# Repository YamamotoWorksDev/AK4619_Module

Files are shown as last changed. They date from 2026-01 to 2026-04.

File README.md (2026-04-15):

# AK4619 Module
This is a module board for prototyping digital synthesizers or mixers, featuring a 4-channel audio codec (AK4619VN) that supports up to 192 kHz.

## How to buy
### 2x2
- [Tindie(International)](https://www.tindie.com/products/yamamotoworks/ak4619vn-codec-module-2x2/)  
- [BASE(Japan)](https://miyworks.base.shop/items/131805475)

### 1x4
- [Tindie(International)](https://www.tindie.com/products/yamamotoworks/ak4619vn-codec-module-1x4/)  
- [BASE(Japan)](https://miyworks.base.shop/items/139583333)

## Specifications
- Power: 5V input, onboard 3.3V regulator (AP7361)
- CODEC IC: [AK4619VN](https://www.akm.com/global/en/products/audio/audio-codec/ak4619vn/)
  - Channels: 4in/4out
  - Sample Rate: 192kHz(max.)
  - TDM Slave (expects external BCLK/LRCLK and MCLK)
- Audio Jack: [Green Thonkiconn Stereo 3.5mm Jack Socket](https://www.thonk.co.uk/shop/thonkiconn/)
- RESET IC: [ADM811](https://www.analog.com/en/products/adm811.html)
- Power IC: [AP7361EA-33E-13](https://www.diodes.com/assets/Datasheets/AP7361EA.pdf)

## Codec Initialization(Example)
```c
void AUDIO_Init_AK4619(uint32_t hz)
{
    uint8_t sndData[1] = {0x00};

    // AK4619 HW Reset
    HAL_GPIO_WritePin(CODEC_RESET_GPIO_Port, CODEC_RESET_Pin, 0);
    HAL_Delay(10);
    HAL_GPIO_WritePin(CODEC_RESET_GPIO_Port, CODEC_RESET_Pin, 1);
    HAL_Delay(500);

    // Audio I/F format
    sndData[0] = 0xAC;  // 1 010 11 00 (TDM, 32bit, TDM128 I2S compatible, Falling, Slow)
    HAL_I2C_Mem_Write(&hi2c3, (0b0010001 << 1), 0x01, I2C_MEMADD_SIZE_8BIT, sndData, sizeof(sndData), 10000);

    // Reset Control
    sndData[0] = 0x10;  // 000 1 00 00
    HAL_I2C_Mem_Write(&hi2c3, (0b0010001 << 1), 0x02, I2C_MEMADD_SIZE_8BIT, sndData, sizeof(sndData), 10000);

    // System Clock Setting (example: 96kHz)
    sndData[0] = 0x01;  // 00000 001 (96kHz)
    HAL_I2C_Mem_Write(&hi2c3, (0b0010001 << 1), 0x03, I2C_MEMADD_SIZE_8BIT, sndData, sizeof(sndData), 10000);

    // ADC Input Setting
    sndData[0] = 0x55;  // 01 01 01 01 (AIN1L, AIN1R, AIN4L, AIN4R)
    HAL_I2C_Mem_Write(&hi2c3, (0b0010001 << 1), 0x0B, I2C_MEMADD_SIZE_8BIT, sndData, sizeof(sndData), 10000);

    // DAC Input Select Setting
    // sndData[0] = 0x0E;  // 00 00 11 10 (ADC1 -> DAC1, ADC2 -> DAC2)
    sndData[0] = 0x04;  // 00 00 01 00 (SDIN2 -> DAC2, SDIN1 -> DAC1)
    HAL_I2C_Mem_Write(&hi2c3, (0b0010001 << 1), 0x12, I2C_MEMADD_SIZE_8BIT, sndData, sizeof(sndData), 10000);

    // Power Management
    sndData[0] = 0x37;  // 00 11 0 11 1
    HAL_I2C_Mem_Write(&hi2c3, (0b0010001 << 1), 0x00, I2C_MEMADD_SIZE_8BIT, sndData, sizeof(sndData), 10000);
}
```

## Application Example
- [JUMBLEQ](https://github.com/yamamo2shun1/JUMBLEQ)

## Size
### 2x2
ak4619_2x2_brd

### 1x4
ak4619_1x4_brd

## Photos
### 2x2
2x2 top
2x2 bottom

### 1x4
1x4 top
1x4 bottom

## License
The hardware design files in this repository are licensed under the
**CERN Open Hardware Licence Version 2 - Permissive (CERN-OHL-P-2.0)**.

Unless otherwise stated, the following are treated as hardware design files covered by CERN-OHL-P-2.0:

- KiCad schematic files
- PCB layout files

A copy of the license text is provided in the `LICENSE` file.

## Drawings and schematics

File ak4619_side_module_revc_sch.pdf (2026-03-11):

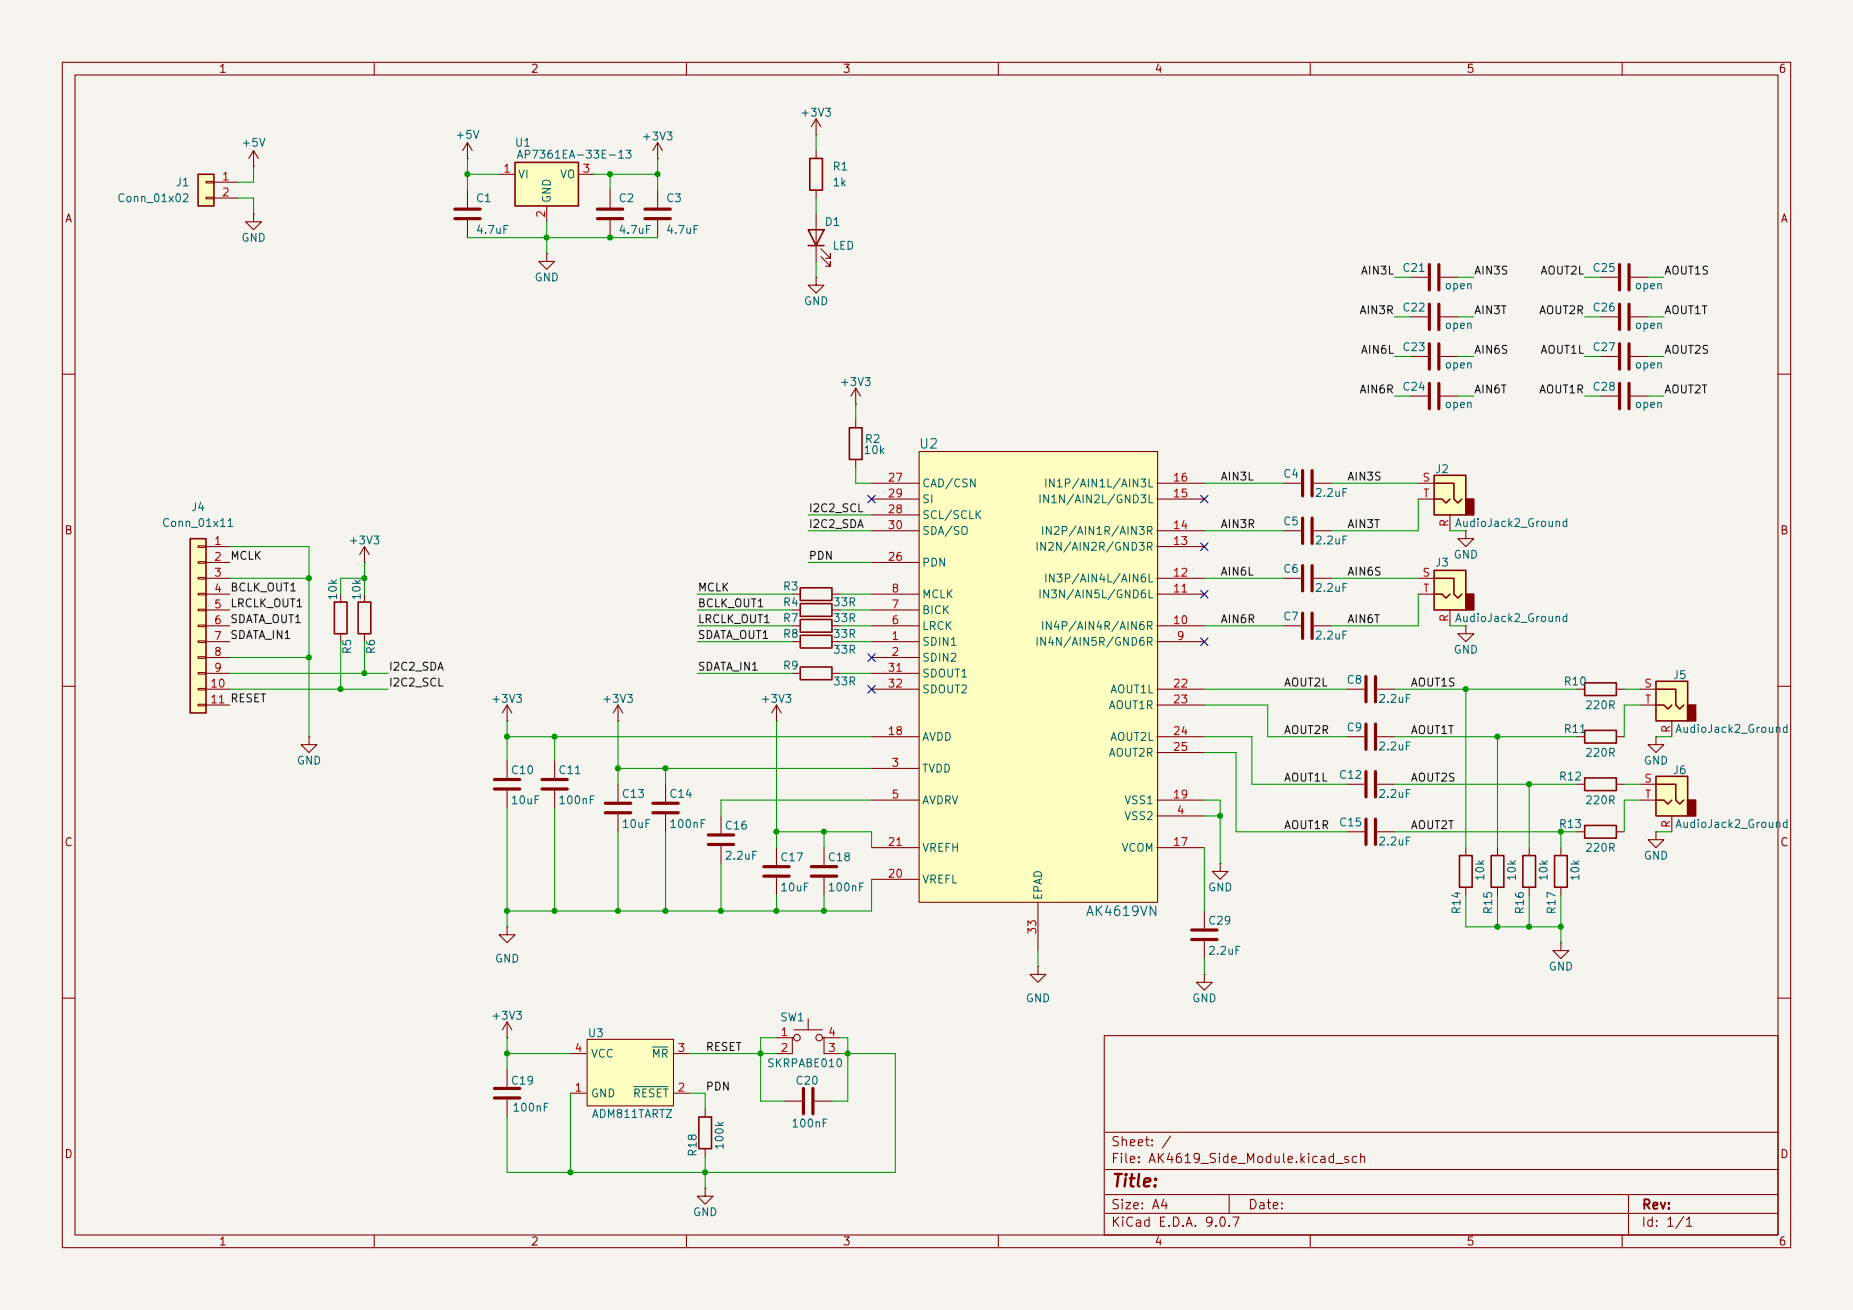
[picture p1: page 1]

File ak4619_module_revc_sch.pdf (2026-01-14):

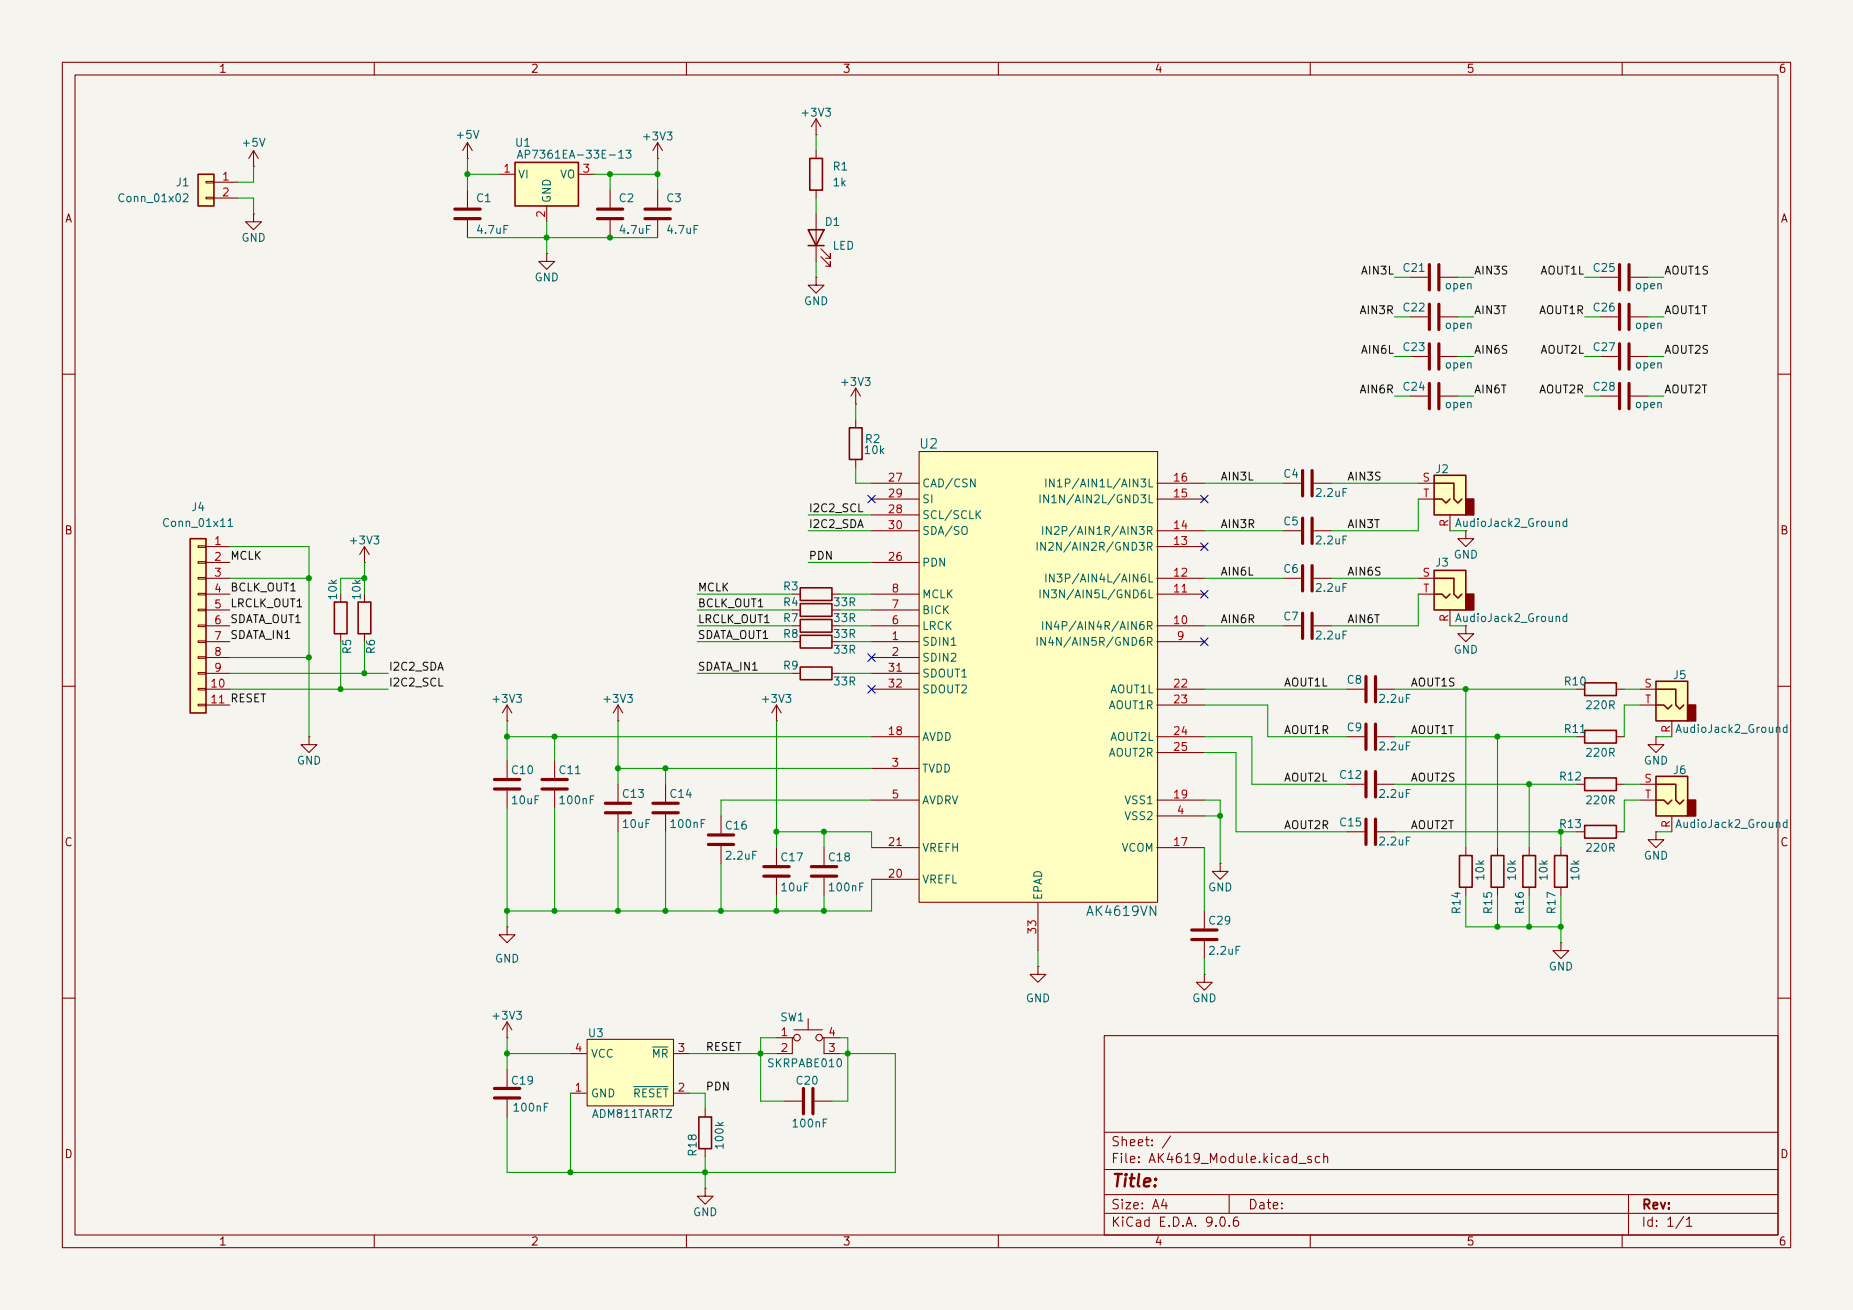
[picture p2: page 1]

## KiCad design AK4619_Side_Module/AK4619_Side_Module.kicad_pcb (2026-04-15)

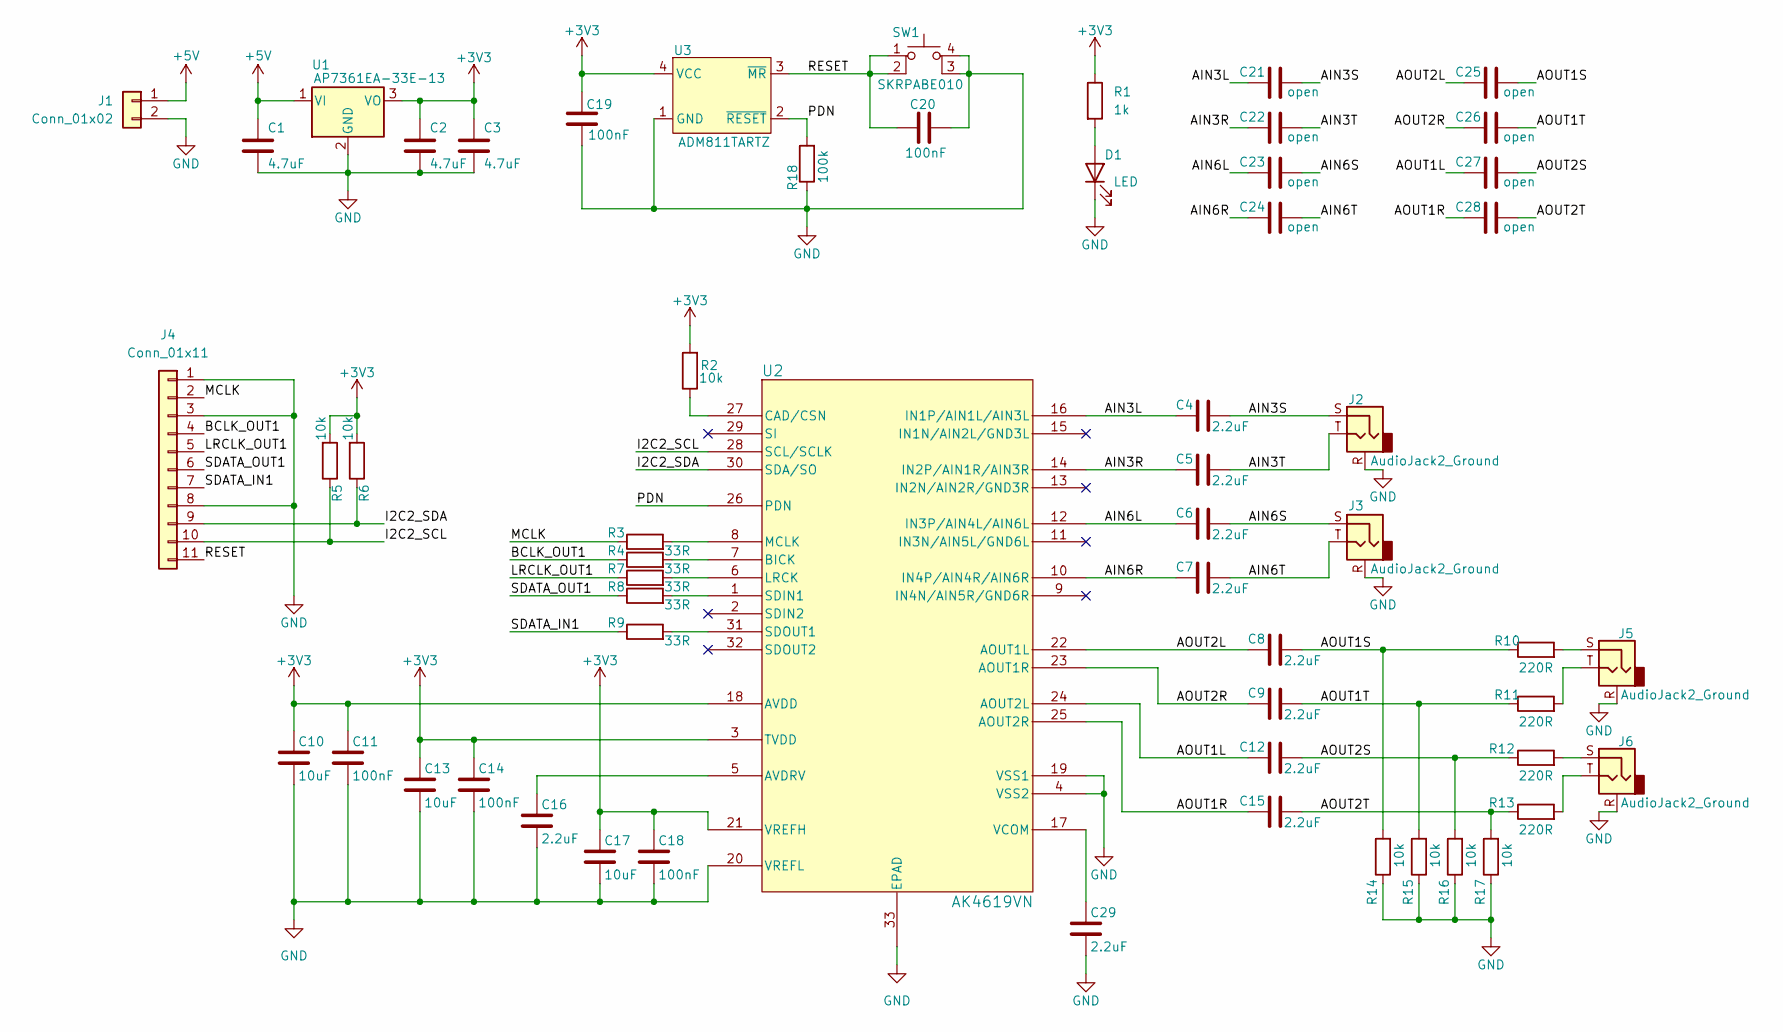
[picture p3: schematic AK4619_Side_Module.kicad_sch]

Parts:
C1, C2, C3: 4.7uF; C_0603_1608Metric
C4, C5, C6, C7, C8, C9, C12, C15: 2.2uF; C_1210_3225Metric_Pad1.33x2.70mm_HandSolder
C10, C13, C17: 10uF; C_0402_1005Metric
C11, C14, C18: 100nF; C_0201_0603Metric
C16, C29: 2.2uF; C_0201_0603Metric
C19, C20: 100nF; C_0402_1005Metric
C21, C22, C23, C24, C25, C26, C27, C28: open; C_1812_4532Metric_Pad1.57x3.40mm_HandSolder
D1: LED; LED_0603_1608Metric
J1: Conn_01x02; JST_PH_B2B-PH-K_1x02_P2.00mm_Vertical
J2, J3, J5, J6: AudioJack2_Ground; Jack_3.5mm_QingPu_WQP-PJ366ST_Vertical
J4: Conn_01x11; PinSocket_1x11_P2.54mm_Vertical
R1: 1k; R_0201_0603Metric
R2, R5, R6: 10k; R_0201_0603Metric
R3, R4, R7, R8, R9: 33R; R_0201_0603Metric
R10, R11, R12, R13: 220R; R_0603_1608Metric_Pad0.98x0.95mm_HandSolder
R14, R15, R16, R17: 10k; R_0201_0603Metric_Pad0.64x0.40mm_HandSolder
R18: 100k; R_0201_0603Metric
SW1: SKRPABE010
U1: AP7361EA-33E-13; SOT-223-3_TabPin2
U2: AK4619VN; AK4619VN_AKM
U3: ADM811TARTZ; SOT-143

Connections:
+3V3: C2.1, C3.1, C10.1, C11.1, C13.1, C14.1, C17.1, C18.1, C19.1, R1.1, R2.2, R5.2, R6.2, U1.3 (VO), U2.3 (TVDD), U2.18 (AVDD), U2.21 (VREFH), U3.4 (VCC)
+5V: C1.1, J1.1, U1.1 (VI)
/AIN3L: C4.1, C21.1, U2.16 (IN1P/AIN1L/AIN3L)
/AIN3R: C5.1, C22.1, U2.14 (IN2P/AIN1R/AIN3R)
/AIN3S: C4.2, C21.2, J2.S
/AIN3T: C5.2, C22.2, J2.T
/AIN6L: C6.1, C23.1, U2.12 (IN3P/AIN4L/AIN6L)
/AIN6R: C7.1, C24.1, U2.10 (IN4P/AIN4R/AIN6R)
/AIN6S: C6.2, C23.2, J3.S
/AIN6T: C7.2, C24.2, J3.T
/AOUT1L: C12.1, C27.1, U2.24 (AOUT2L)
/AOUT1R: C15.1, C28.1, U2.25 (AOUT2R)
/AOUT1S: C8.2, C25.2, R10.1, R14.2
/AOUT1T: C9.2, C26.2, R11.1, R15.2
/AOUT2L: C8.1, C25.1, U2.22 (AOUT1L)
/AOUT2R: C9.1, C26.1, U2.23 (AOUT1R)
/AOUT2S: C12.2, C27.2, R12.1, R16.2
/AOUT2T: C15.2, C28.2, R13.1, R17.2
/BCLK_OUT1: J4.4, R4.1
/I2C2_SCL: J4.10, R5.1, U2.28 (SCL/SCLK)
/I2C2_SDA: J4.9, R6.1, U2.30 (SDA/SO)
/LRCLK_OUT1: J4.5, R7.1
/MCLK: J4.2, R3.1
/PDN: R18.2, U2.26 (PDN), U3.2 (~RESET)
/RESET: C20.1, J4.11, SW1.1, SW1.2, U3.3 (~MR)
/SDATA_IN1: J4.7, R9.1
/SDATA_OUT1: J4.6, R8.1
GND: C1.2, C2.2, C3.2, C10.2, C11.2, C13.2, C14.2, C16.2, C17.2, C18.2, C19.2, C20.2, C29.2, D1.1 (K), J1.2, J2.R, J3.R, J4.1, J4.3, J4.8, J5.R, J6.R, R14.1, R15.1, R16.1, R17.1, R18.1, SW1.3 (K), SW1.4 (A), U1.2 (GND), U2.4 (VSS2), U2.19 (VSS1), U2.20 (VREFL), U2.33 (EPAD), U3.1 (GND)
unnamed: D1.2 (A), R1.2
unnamed: J5.S, R10.2
unnamed: J5.T, R11.2
unnamed: J6.S, R12.2
unnamed: J6.T, R13.2
unnamed: C16.1, U2.5 (AVDRV)
unnamed: R4.2, U2.7 (BICK)
unnamed: R2.1, U2.27 (CAD/CSN)
unnamed: R7.2, U2.6 (LRCK)
unnamed: R3.2, U2.8 (MCLK)
unnamed: R8.2, U2.1 (SDIN1)
unnamed: R9.2, U2.31 (SDOUT1)
unnamed: C29.1, U2.17 (VCOM)

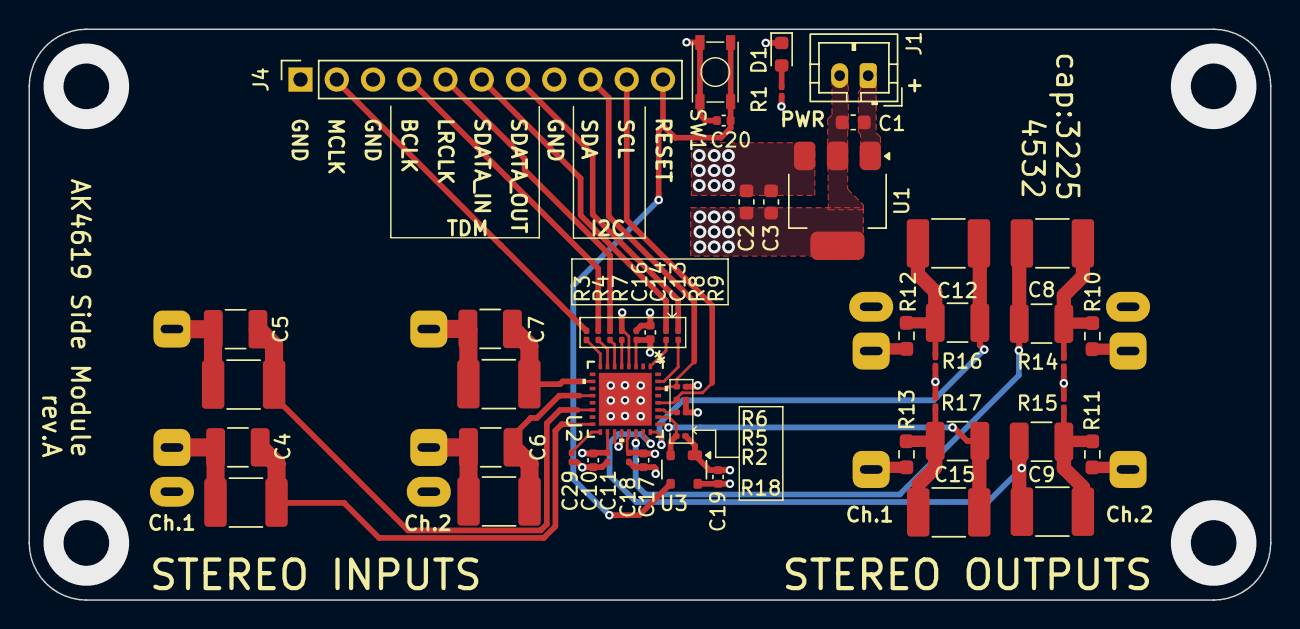
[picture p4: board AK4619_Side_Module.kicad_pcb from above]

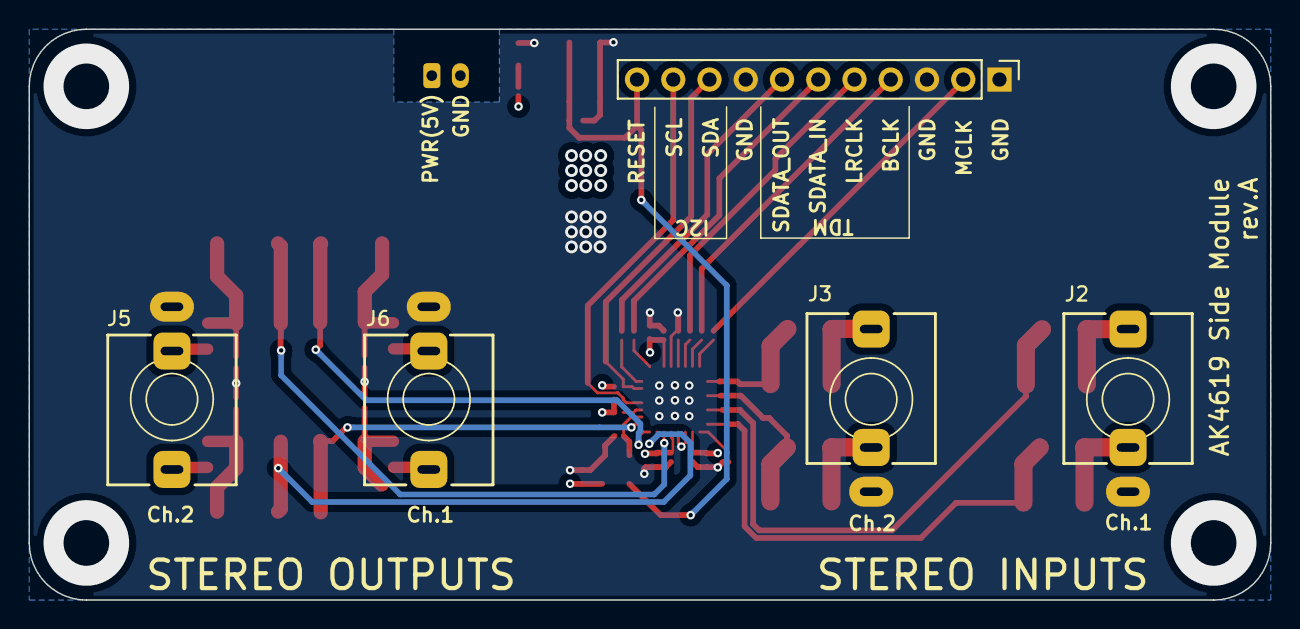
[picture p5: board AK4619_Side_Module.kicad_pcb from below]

Board: 4 copper layers, 87.0 x 40.0 mm, 58 parts (4 on the bottom side), 41 nets.

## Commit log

2026-01-13 Add Kicad project files.
    [AK4619_Module.kicad_pcb, AK4619_Module.kicad_sch]
2026-01-13 Add schematic.
2026-01-14 C4,5,6,7,8,9,12,15の値を修正
    [AK4619_Module.kicad_sch]
2026-03-10 Modify the silk in the Bottom Layer
    [AK4619_Module.kicad_pcb]
2026-03-11 Add Kicad projects(side panel version)
    [AK4619_Side_Module.kicad_pcb, AK4619_Side_Module.kicad_sch]
2026-03-11 Add dimension annotations to the PCB data.
    [AK4619_Side_Module.kicad_pcb]
2026-03-12 Change the 3D model data path settings.
    [AK4619_Module.kicad_pcb, AK4619_Side_Module.kicad_pcb]
2026-04-15 Clean up symbol placement
    [AK4619_Side_Module.kicad_sch]
2026-04-15 Add dimension annotations
    [AK4619_Module.kicad_pcb, AK4619_Side_Module.kicad_pcb]
